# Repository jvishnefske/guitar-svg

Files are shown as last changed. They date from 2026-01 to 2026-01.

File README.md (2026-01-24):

# Guitar CAD Project

FreeCAD-based guitar design with Git-friendly version control.

## FreeCAD Setup

Set compression level to 0 so git can delta-compress FCStd files efficiently:

**Edit > Preferences > General > Document > Compression level = 0**

FCStd files are ZIP archives. At compression level 0 (STORED), the XML
content inside is uncompressed, which lets git's packfile delta compression
detect byte-level similarities between revisions without any extra tooling.

## Git Setup

Configure the textconv diff driver to see meaningful diffs of FCStd files:

```bash
git config diff.fcstd.textconv 'python3 -c "import zipfile,sys;z=zipfile.ZipFile(sys.argv[1]);[print(z.read(f).decode()) for f in sorted(z.namelist()) if f.endswith(\".xml\")]"'
```

This extracts and prints all XML files from the FCStd archive, letting
`git diff` show text diffs of the underlying Document.xml and GuiDocument.xml.

## Directory Structure

```
3d/
  stratocaster.FCStd   # FreeCAD model (tracked, zip level 0)
  cam.py               # CAM toolpath generation script
reference/             # Reference drawings and measurements
templates/             # Templates and patterns
```

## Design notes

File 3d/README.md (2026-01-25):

# 3D / CAM

**Warning:** G-code output is untested and has known and possibly unknown errors. The perimeter profile operation does not compensate for tool width — the cut follows the exact model outline rather than offsetting by the tool radius.

## Scripts

- `fix_pockets.py` — Fixes pocket sketch attachments to XY_Plane with a Z offset, then creates the NeckPocket and ControlsPocket features in the PartDesign body.
- `cam.py` — Generates CAM toolpaths (profile and pocket operations) and exports to ShopBot `.sbp` format.

Run `fix_pockets.py` first (it creates the pocket features that `cam.py` references).

### Execution

```
flatpak run --command=FreeCADCmd org.freecad.FreeCAD fix_pockets.py
flatpak run --command=FreeCADCmd org.freecad.FreeCAD cam.py
```

## Tool Parameters

| Parameter | Value |
|---|---|
| Endmill diameter  | 12.7 mm (1/2") |
| Cutting edge | 30 mm |
| Spindle speed | 18000 RPM |
| Horizontal feed | 1500 mm/min |
| Vertical feed | 500 mm/min |
| Step down | 6 mm per pass |
| Step over (pocket) | 50% |

## CAM Operations

- **Perimeter profile** — Through-cut (45 mm) with outside contour, CW direction. Empty Base triggers contour mode which profiles the full model outline.
- **Pocket operations** — One per `PartDesign::Pocket` feature. Uses face detection at the pocket floor Z level to assign base geometry. Through-cut pockets fall back to wall-face detection.
- **Bottom-side pockets** — Profiled from the top face as inside-contour slots, leaving a 1 mm margin at the bottom.

Output format is ShopBot `.sbp` via the `opensbp_post.py` post-processor.

## Sketch Documentation

The FreeCAD model uses auto-generated sketch names. Their actual purposes:

| Sketch Name  | Purpose | Pocket Depth  |
|---|---|---|
| `Sketch` | Body perimeter (used for Pad) | N/A |
| `Sketch001`  | Neck pocket | 15.875 mm |
| `Sketch003`  | Controls cavity | 38.1 mm |

Sketch attachment offsets use identity quaternions `(0, 0, 0, 1)` — no actual rotation is applied.

## Known Limitations

- Perimeter profile does not offset by tool radius; the resulting cut will be undersized by one tool diameter.
- Some pocket operations may produce no toolpath if face detection fails — these need manual base geometry assignment in the FreeCAD GUI.

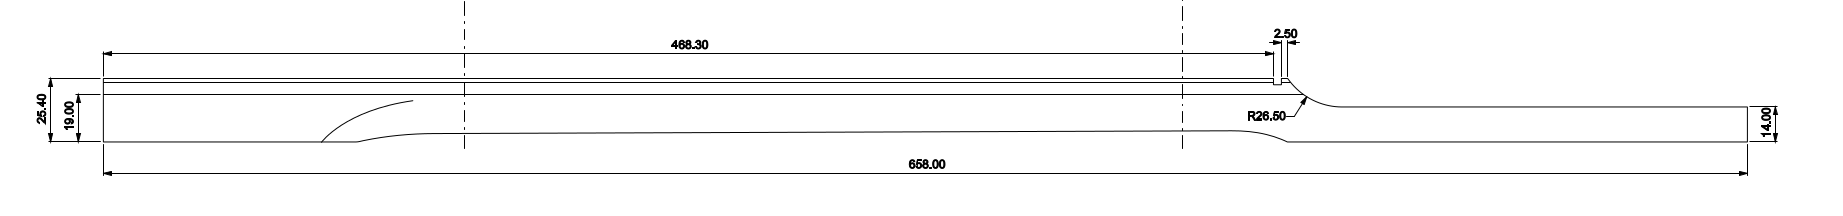
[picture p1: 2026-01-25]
reference/neck/side-neck.png

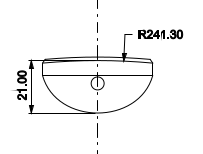
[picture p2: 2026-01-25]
reference/neck/profile-1st-fret.png

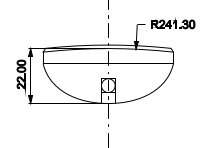
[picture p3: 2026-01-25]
reference/neck/profile-12th-fret.png

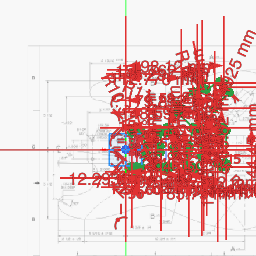
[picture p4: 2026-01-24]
3d/body.fcstd.d/thumbnails/Thumbnail.png

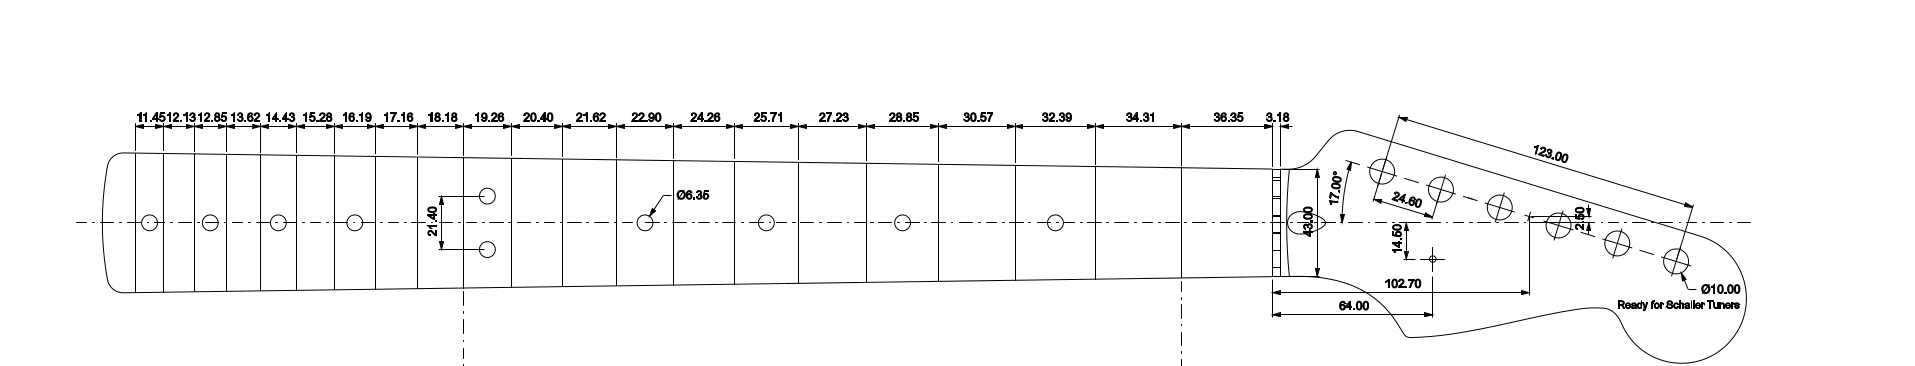
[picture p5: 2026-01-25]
reference/neck/top-neck.png

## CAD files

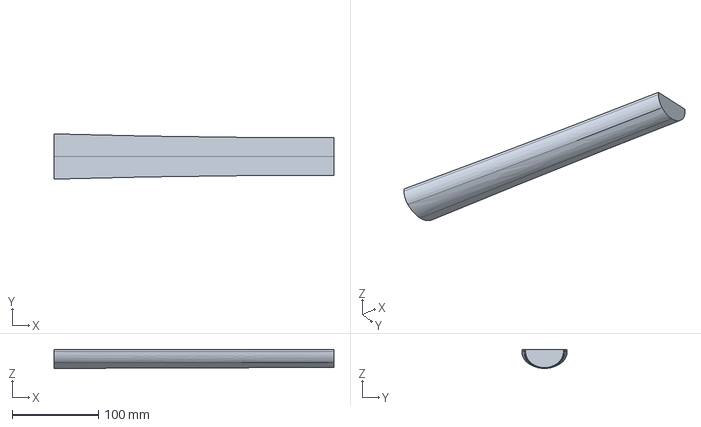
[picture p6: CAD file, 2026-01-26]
3d/neck.FCStd
323.9 x 52.3 x 22.0 mm

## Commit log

2026-01-24 add tool radius compensation to profile operations
    Enable UseComp on perimeter and bridge slot profiles so the tool
    path is offset by the cutter radius, cutting to true geometry edges.
2026-01-24 Replace explode/implode workflow with zip level 0 approach
    FCStd files saved at compression level 0 (STORED) let git's packfile
    delta compression work directly on the archive contents. Added textconv
    diff driver config and CI check to enforce uncompressed storage.
2026-01-25 neck
    includes py scripts of dubious quality
    [neck.FCStd]
2026-01-26 intermediate neck cross sections
    [neck.FCStd]
